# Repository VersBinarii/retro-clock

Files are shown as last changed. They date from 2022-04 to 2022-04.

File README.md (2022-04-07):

# Retro Clock

Nixie clock based on stm32f103 "BluePill"

# Description

Its based on stm32f103 RTC peripheral.
The nixie valves are driven with 74LS145 BCD to decimal decoder
The time is outputed through the NIXIE as wel as through the smal I2C based OLED.

# Operation

Long press 'Ok' putton to enter into edit mode. 
Then short press selects the digit to edit. 'Left' and 'Right' buttons increase/decrease the value.
Long press 'Ok' again to confirm new time.

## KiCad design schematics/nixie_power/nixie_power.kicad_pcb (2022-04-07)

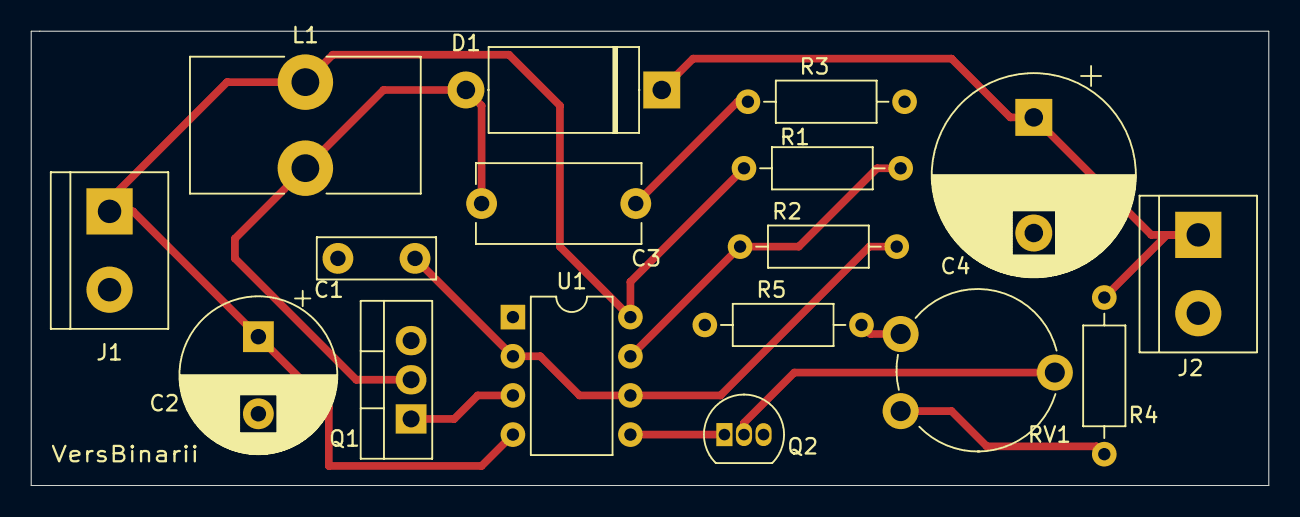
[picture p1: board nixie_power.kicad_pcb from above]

Board: 2 copper layers, 80.3 x 29.5 mm, 17 parts (0 on the bottom side), 12 nets.

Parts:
C1: 2n2; C_Disc_D7.5mm_W2.5mm_P5.00mm
C2: 470uF/250V; CP_Radial_D10.0mm_P5.00mm
C3: 100p/400V; C_Disc_D10.5mm_W5.0mm_P10.00mm
C4: 15u/350V; CP_Radial_D13.0mm_P7.50mm
D1: 400V/2A; D_DO-27_P12.70mm_Horizontal
J1, J2: Screw_Terminal_01x02; TerminalBlock_bornier-2_P5.08mm
L1: 100mH; L_Toroid_Vertical_L14.7mm_W8.6mm_P5.58mm_Pulse_KM-1
Q1: IRF740; TO-220-3_Vertical
Q2: BC547; TO-92_Inline
R1: 1K; R_Axial_DIN0207_L6.3mm_D2.5mm_P10.16mm_Horizontal
R2: 10K; R_Axial_DIN0207_L6.3mm_D2.5mm_P10.16mm_Horizontal
R3: 47R; R_Axial_DIN0207_L6.3mm_D2.5mm_P10.16mm_Horizontal
R4: 220K; R_Axial_DIN0207_L6.3mm_D2.5mm_P10.16mm_Horizontal
R5: 470; R_Axial_DIN0207_L6.3mm_D2.5mm_P10.16mm_Horizontal
RV1: 1k; Potentiometer_Piher_PT-10-V10_Vertical
U1: NE555P; DIP-8_W7.62mm

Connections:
GND: C1.2, C2.2, C4.2, J1.2, J2.2, Q1.3, Q2.3, R3.2, R5.2, U1.1
unnamed: C1.1, R2.2, U1.2, U1.6
unnamed: C2.1, J1.1, L1.1, R1.1, U1.4, U1.8
unnamed: C3.1, D1.2, L1.2, Q1.2
unnamed: C3.2, R3.1
unnamed: C4.1, D1.1, J2.1, R4.1
unnamed: Q1.1, U1.3
unnamed: Q2.1, U1.5
unnamed: Q2.2, RV1.2
unnamed: R1.2, R2.1, U1.7
unnamed: R4.2, RV1.1
unnamed: R5.1, RV1.3

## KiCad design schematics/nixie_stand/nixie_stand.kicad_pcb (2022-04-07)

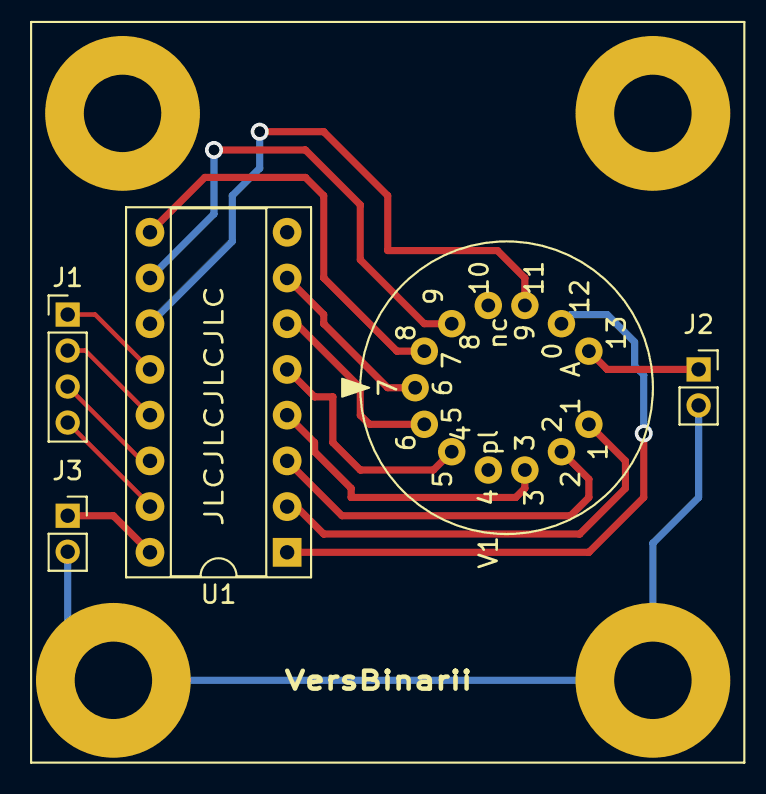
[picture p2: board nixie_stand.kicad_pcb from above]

Board: 2 copper layers, 9 parts (0 on the bottom side), 17 nets.

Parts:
H1, H2, H3, H4: MountingHole_Pad; MountingHole_4.3mm_M4_Pad
J1: Conn_01x04; PinHeader_1x04_P2.00mm_Vertical
J2, J3: Conn_01x02; PinSocket_1x02_P2.00mm_Vertical
U1: 74LS145; DIP-16_W7.62mm_Socket
V1: Z574M; nixie_z574m

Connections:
+5V: J3.1, U1.16
GND: H1.1, H2.1, H3.1, H4.1, J2.2, J3.2, U1.8
unnamed: J1.1, U1.12
unnamed: J1.2, U1.13
unnamed: J1.3, U1.14
unnamed: J1.4, U1.15
unnamed: U1.1, V1.12
unnamed: U1.2, V1.1
unnamed: U1.3, V1.2
unnamed: U1.4, V1.3
unnamed: U1.5, V1.5
unnamed: U1.6, V1.6
unnamed: U1.7, V1.7
unnamed: U1.9, V1.8
unnamed: U1.10, V1.9
unnamed: U1.11, V1.11
VCC: J2.1, V1.13

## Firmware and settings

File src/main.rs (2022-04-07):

#![no_std]
#![no_main]

mod clock;
mod display;
mod gui;
mod nixie;

use panic_halt as _;

#[rtic::app(device = stm32f1xx_hal::pac, peripherals=true)]
mod app {

    use crate::{
        clock::RtcClock,
        display::Display,
        gui::Gui,
        nixie::{NibbleWriter, NixieDriver},
    };
    use panic_halt as _;
    use ssd1306::{prelude::*, size::DisplaySize128x32, I2CDisplayInterface, Ssd1306};
    use stm32f1xx_hal::{
        gpio::{
            gpioa::{PA0, PA1, PA11, PA12, PA15, PA2, PA3, PA4, PA5, PA6, PA7},
            gpiob::{PB10, PB11, PB12, PB13, PB14, PB15, PB4, PB5, PB6, PB7},
            gpioc::PC13,
            Alternate, Edge, ExtiPin, Input, OpenDrain, Output, PullUp, PushPull,
        },
        i2c::{BlockingI2c, DutyCycle, Mode},
        pac::{I2C2, TIM3},
        prelude::*,
        rtc::Rtc,
        timer::{delay::SysDelay, CounterHz, Event},
    };
    use ufmt::derive::uDebug;

    type OledScl = PB10<Alternate<OpenDrain>>;
    type OledSda = PB11<Alternate<OpenDrain>>;
    type GuiInterface = Gui<I2CInterface<BlockingI2c<I2C2, (OledScl, OledSda)>>, DisplaySize128x32>;
    type OutputPP = Output<PushPull>;

    #[derive(uDebug, Copy, Clone)]
    pub enum PressedButton {
        Left,
        Right,
        ShortPress,
        LongPress,
        None,
    }

    pub struct Buttons {
        enter: PA15<Input<PullUp>>,
        left: PA11<Input<PullUp>>,
        right: PA12<Input<PullUp>>,
    }

    #[shared]
    struct SharedResource {
        led: PC13<OutputPP>,
        tim: CounterHz<TIM3>,
        delay: SysDelay,
        buttons: Buttons,
        gui: GuiInterface,
        clock: RtcClock,
        pressed_btn: PressedButton,
        press_counter: u8,
    }

    #[local]
    struct LocalResource {
        nixie_driver: NixieDriver<
            PB12<OutputPP>,
            PB13<OutputPP>,
            PB14<OutputPP>,
            PB15<OutputPP>,
            PB4<OutputPP>,
            PB5<OutputPP>,
            PB6<OutputPP>,
            PB7<OutputPP>,
            PA4<OutputPP>,
            PA5<OutputPP>,
            PA6<OutputPP>,
            PA7<OutputPP>,
            PA0<OutputPP>,
            PA1<OutputPP>,
            PA2<OutputPP>,
            PA3<OutputPP>,
        >,
    }

    #[init]
    fn init(cx: init::Context) -> (SharedResource, LocalResource, init::Monotonics) {
        let cp = cx.core;
        let mut dp = cx.device;

        let mut flash = dp.FLASH.constrain();
        let rcc = dp.RCC.constrain();
        let mut afio = dp.AFIO.constrain();
        let clocks = rcc
            .cfgr
            .use_hse(8.MHz())
            .sysclk(48.MHz())
            .pclk1(6.MHz())
            .freeze(&mut flash.acr);

        let mut gpioc = dp.GPIOC.split();
        let mut gpioa = dp.GPIOA.split();
        let mut gpiob = dp.GPIOB.split();

        /*
         * Led indicator flashing every second to show all OK
         */
        let led = gpioc.pc13.into_push_pull_output(&mut gpioc.crh);

        /*
         * Timer used to count the length of
         * time seconds button is pressed
         */
        let mut timer3 = dp.TIM3.counter_hz(&clocks);
        timer3.start(1.Hz()).unwrap();
        timer3.listen(Event::Update);

        /*
         * General purpose delay
         */
        let delay = cp.SYST.delay(&clocks);

        /*
         *  I2C config for OLED display
         *  PB10 -> SCL
         *  PB11 -> SDA
         */

        let oled_scl = gpiob.pb10.into_alternate_open_drain(&mut gpiob.crh);
        let oled_sda = gpiob.pb11.into_alternate_open_drain(&mut gpiob.crh);
        let oled_i2c = BlockingI2c::i2c2(
            dp.I2C2,
            (oled_scl, oled_sda),
            Mode::Fast {
                frequency: 400_000.Hz(),
                duty_cycle: DutyCycle::Ratio2to1,
            },
            clocks,
            1000,
            10,
            1000,
            1000,
        );
        let interface = I2CDisplayInterface::new(oled_i2c);
        let mut oled = Ssd1306::new(interface, DisplaySize128x32, DisplayRotation::Rotate180)
            .into_buffered_graphics_mode();
        oled.init().unwrap();
        let display = Display::new(oled);
        let gui = Gui::new(display);

        /*
         * Bunch of buttons for setting up of the clock time
         */
        let (pa15, _, pb4) = afio.mapr.disable_jtag(gpioa.pa15, gpiob.pb3, gpiob.pb4);
        let mut enter = pa15.into_pull_up_input(&mut gpioa.crh);
        enter.make_interrupt_source(&mut afio);
        enter.trigger_on_edge(&dp.EXTI, Edge::RisingFalling);
        enter.enable_interrupt(&dp.EXTI);
        let mut left = gpioa.pa11.into_pull_up_input(&mut gpioa.crh); // PA11
        left.make_interrupt_source(&mut afio);
        left.trigger_on_edge(&dp.EXTI, Edge::Falling);
        left.enable_interrupt(&dp.EXTI);
        let mut right = gpioa.pa12.into_pull_up_input(&mut gpioa.crh); //PA12
        right.make_interrupt_source(&mut afio);
        right.trigger_on_edge(&dp.EXTI, Edge::Falling);
        right.enable_interrupt(&dp.EXTI);

        let buttons = Buttons { enter, left, right };

        // Initialize RTC
        let mut backup_domain = rcc.bkp.constrain(dp.BKP, &mut dp.PWR);
        let rtc = Rtc::new(dp.RTC, &mut backup_domain);
        let clock = RtcClock::new(rtc);

        /*
         *  Configure pins used for driving the Nixie tubes
         */
        let min_u_d0 = gpioa.pa0.into_push_pull_output(&mut gpioa.crl);
        let min_u_d1 = gpioa.pa1.into_push_pull_output(&mut gpioa.crl);
        let min_u_d2 = gpioa.pa2.into_push_pull_output(&mut gpioa.crl);
        let min_u_d3 = gpioa.pa3.into_push_pull_output(&mut gpioa.crl);
        let min_u = NibbleWriter::new(min_u_d0, min_u_d1, min_u_d2, min_u_d3);

        let min_t_d0 = gpioa.pa4.into_push_pull_output(&mut gpioa.crl);
        let min_t_d1 = gpioa.pa5.into_push_pull_output(&mut gpioa.crl);
        let min_t_d2 = gpioa.pa6.into_push_pull_output(&mut gpioa.crl);
        let min_t_d3 = gpioa.pa7.into_push_pull_output(&mut gpioa.crl);
        let min_t = NibbleWriter::new(min_t_d0, min_t_d1, min_t_d2, min_t_d3);

        let hour_u_d0 = pb4.into_push_pull_output(&mut gpiob.crl);
        let hour_u_d1 = gpiob.pb5.into_push_pull_output(&mut gpiob.crl);
        let hour_u_d2 = gpiob.pb6.into_push_pull_output(&mut gpiob.crl);
        let hour_u_d3 = gpiob.pb7.into_push_pull_output(&mut gpiob.crl);
        let hour_u = NibbleWriter::new(hour_u_d0, hour_u_d1, hour_u_d2, hour_u_d3);

        let hour_t_d0 = gpiob.pb12.into_push_pull_output(&mut gpiob.crh);
        let hour_t_d1 = gpiob.pb13.into_push_pull_output(&mut gpiob.crh);
        let hour_t_d2 = gpiob.pb14.into_push_pull_output(&mut gpiob.crh);
        let hour_t_d3 = gpiob.pb15.into_push_pull_output(&mut gpiob.crh);
        let hour_t = NibbleWriter::new(hour_t_d0, hour_t_d1, hour_t_d2, hour_t_d3);

        let nixie_driver = NixieDriver::new(hour_t, hour_u, min_t, min_u);
        (
            SharedResource {
                led,
                tim: timer3,
                delay,
                gui,
                buttons,
                clock,
                press_counter: 0,
                pressed_btn: PressedButton::None,
            },
            LocalResource { nixie_driver },
            init::Monotonics(),
        )
    }

    #[idle(shared = [delay, gui, clock, pressed_btn], local=[nixie_driver])]
    fn idle(cx: idle::Context) -> ! {
        let delay = cx.shared.delay;
        let gui = cx.shared.gui;
        let clock = cx.shared.clock;
        let mut pressed_btn = cx.shared.pressed_btn;
        let nixie_driver = cx.local.nixie_driver;
        (clock, gui, delay).lock(|clock, gui, delay| {
            // draw stuff here
            loop {
                // Update buttons
                let pb = pressed_btn.lock(|pb| *pb);
                match pb {
                    PressedButton::Left => {
                        gui.backward();
                        pressed_btn.lock(|pb| *pb = PressedButton::None);
                    }
                    PressedButton::Right => {
                        gui.forward();
                        pressed_btn.lock(|pb| *pb = PressedButton::None);
                    }
                    PressedButton::LongPress => {
                        gui.edit_clock(clock);
                        pressed_btn.lock(|pb| *pb = PressedButton::None);
                    }
                    PressedButton::ShortPress => {
                        gui.select();
                        pressed_btn.lock(|pb| *pb = PressedButton::None);
                    }
                    _ => {}
                };

                gui.print_clock(clock);
                let time = clock.get_time();
                nixie_driver.show(&time);

                delay.delay_ms(500u32);
            }
        })
    }

    #[task(binds = EXTI15_10, shared = [buttons, press_counter, pressed_btn])]
    fn exti15_10(cx: exti15_10::Context) {
        let buttons = cx.shared.buttons;
        let press_counter = cx.shared.press_counter;
        let pressed_btn = cx.shared.pressed_btn;

        (buttons, press_counter, pressed_btn).lock(|buttons, pc, pb| {
            let Buttons { enter, left, right } = buttons;
            if enter.check_interrupt() {
                if enter.is_low() {
                    /* Reset counter on buton press */
                    *pc = 0;
                } else if *pc > 3 && enter.is_high() {
                    /* If the button was held for 3 seconds its a Long press */
                    *pb = PressedButton::LongPress;
                } else {
                    *pb = PressedButton::ShortPress;
                }
            } else if left.check_interrupt() && left.is_low() {
                *pb = PressedButton::Left;
            } else if right.check_interrupt() && right.is_low() {
                *pb = PressedButton::Right;
            }

            enter.clear_interrupt_pending_bit();
            left.clear_interrupt_pending_bit();
            right.clear_interrupt_pending_bit();
        })
    }

    #[task(binds = TIM3, shared = [led, tim, press_counter])]
    fn tim3(mut cx: tim3::Context) {
        let _ = cx.shared.led.lock(|led| led.toggle());
        let _ = cx.shared.tim.lock(|tim| tim.wait());
        cx.shared.press_counter.lock(|pc| *pc += 1);
    }
}
